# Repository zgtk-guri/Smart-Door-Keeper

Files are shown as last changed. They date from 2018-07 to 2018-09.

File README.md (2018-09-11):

### トランジスタ技術 IoT製作コーナー
## NFCカードリーダ×Wi-Fi/Bluetoothマイコンで作るIoT電子錠
# 「Smart Door Keeper」ダウンロードページ

## 2018年9月号 前編 NFCの仕組みとハードウェア製作
* [3Dプリントファイル](3DPrint/README.md)
* [回路図・基板パターン](Circuit/README.md)

## 2018年10月号 後編
* [ESP32のプログラム(Platform IO, Arduino Core使用)](https://github.com/zgtk-guri/Smart-Door-Keeper-ESP32/tree/toragi1810)
* [Androidアプリのプログラム](https://github.com/zgtk-guri/Smart-Door-Keeper-Android/tree/toragi1810)

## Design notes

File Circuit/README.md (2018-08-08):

# Smart Door Keeper 回路図・基板パターンファイル

* [SmartDoorKeeper.pro](SmartDoorKeeper.pro) KiCad 4.0.7 プロジェクトファイル
* [SmartDoorKeeper.sch](SmartDoorKeeper.sch) Eeschema 回路図ファイル
* [SmartDoorKeeper-schematic.pdf](SmartDoorKeeper-schematic.pdf) 回路図PDFファイル
* [SmartDoorKeeper.kicad_pcb](SmartDoorKeeper.kicad_pcb) Pcbnew 基板パターンファイル

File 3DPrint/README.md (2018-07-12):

# Smart Door Keyper 3Dプリントファイル

* SOLIDWORKS 2017で設計
* 3Dプリンタで出力する際に，サポート材が生成されないように分割ししてSTLにしている部品がある

## 分解図（組み立てイメージ）
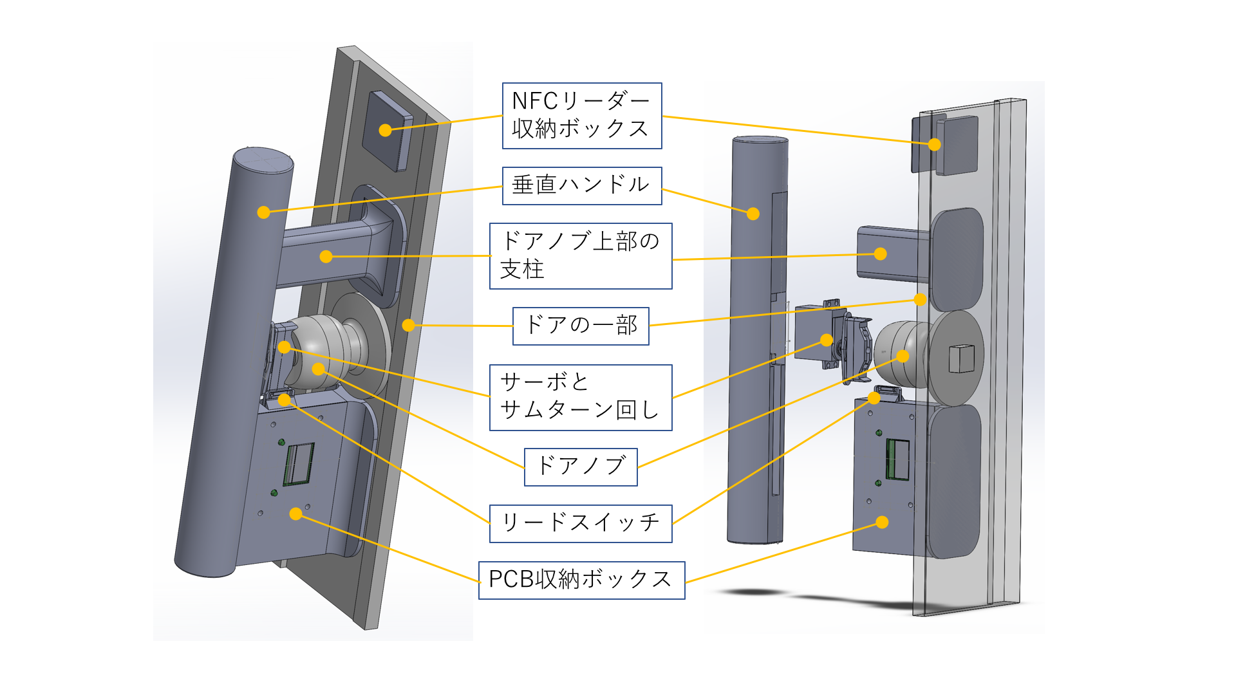
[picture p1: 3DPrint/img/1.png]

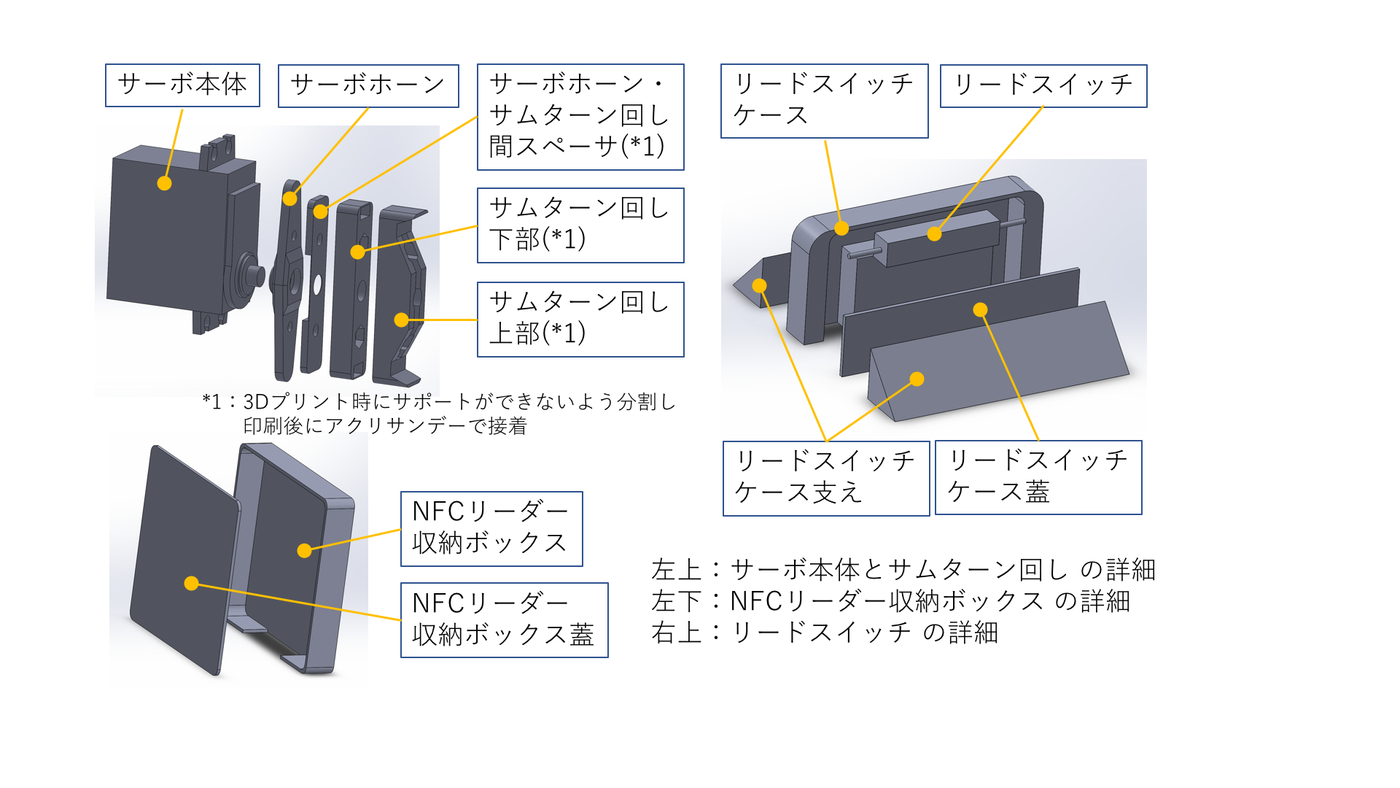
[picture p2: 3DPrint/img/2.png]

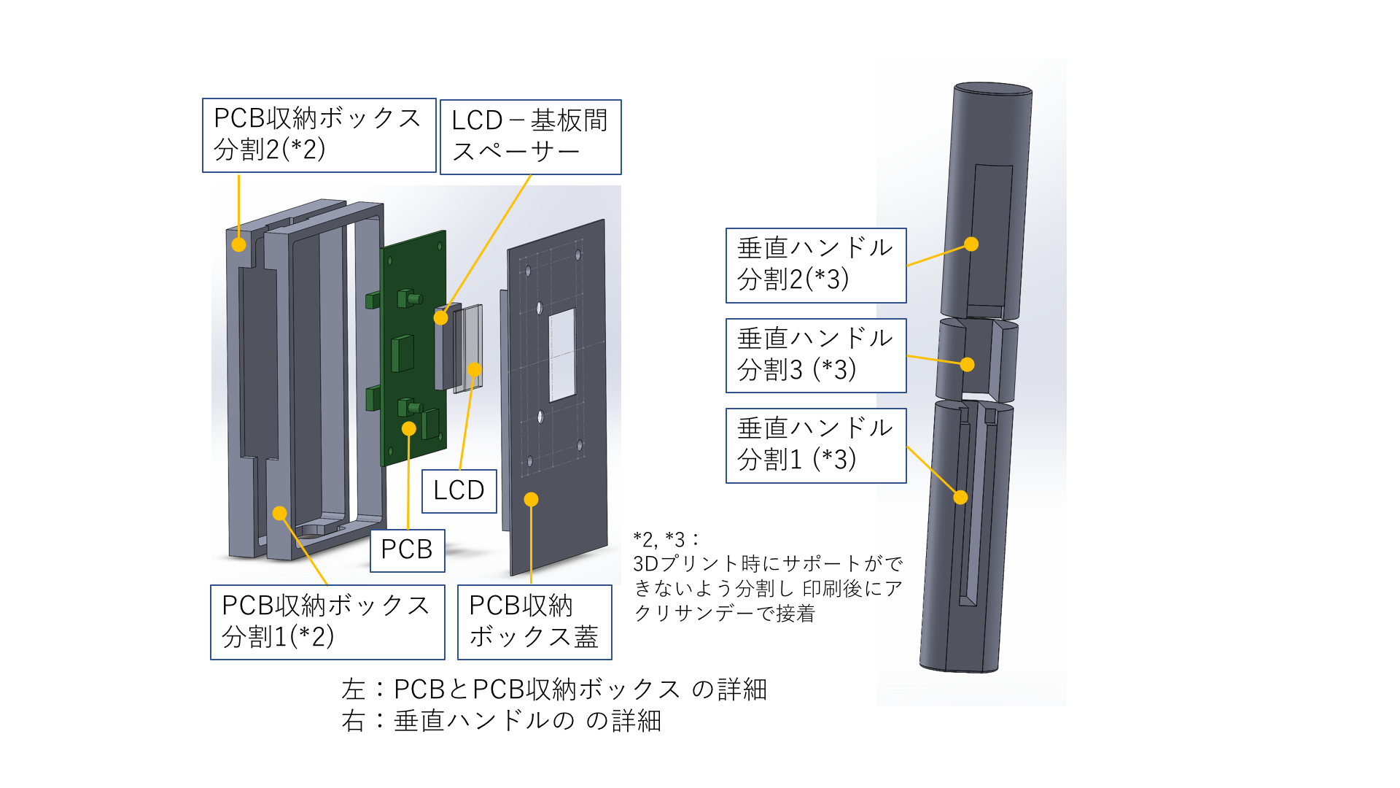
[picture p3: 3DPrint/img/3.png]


## ファイル一覧

<table>
  <tr>
    <th colspan="3">SolidWorks2017で作成した図面</th>
    <th colspan="2">3Dプリンタ用STLファイル</th>
  </tr>
  <tr>
    <td><a href="Solidworks/AssemDoorAndServo.SLDASM">AssemDoorAndServo.SLDASM</a>
    <td>組立図</td>
    <td>全組立図</td>
    <td></td>
    <td></td>
  </tr>
  <tr>
    <td><a href="Solidworks/AssemDoorKnob.SLDASM">AssemDoorKnob.SLDASM</a>
    <td>組立図</td>
    <td>ドアノブ</td>
    <td></td>
    <td></td>
  </tr>
  <tr>
    <td><a href="Solidworks/AssemNfcBox.SLDASM">AssemNfcBox.SLDASM</a>
    <td>組立図</td>
    <td>NFCリーダー収納ボックス</td>
    <td></td>
    <td></td>
  </tr>
  <tr>
    <td><a href="Solidworks/AssemPrintCircuitBoardAndLid.SLDASM">AssemPrintCircuitBoardAndLid.SLDASM</a>
    <td>組立図</td>
    <td>基板と基板収納ボックスの蓋</td>
    <td></td>
    <td></td>
  </tr>
  <tr>
    <td><a href="Solidworks/AssemPrintCircuitBoardBox.SLDASM">AssemPrintCircuitBoardBox.SLDASM</a>
    <td>組立図</td>
    <td>基板収納ボックスと基板</td>
    <td></td>
    <td></td>
  </tr>
  <tr>
    <td><a href="Solidworks/AssemPrintCuircuitBoard.SLDASM">AssemPrintCuircuitBoard.SLDASM</a>
    <td>組立図</td>
    <td>PCB</td>
    <td></td>
    <td></td>
  </tr>
  <tr>
    <td><a href="Solidworks/AssemReedSwitchCase.SLDASM">AssemReedSwitchCase.SLDASM</a>
    <td>組立図</td>
    <td>リードスイッチとケース</td>
    <td></td>
    <td></td>
  </tr>
  <tr>
    <td><a href="Solidworks/AssemServo.SLDASM">AssemServo.SLDASM</a>
    <td>組立図</td>
    <td>サーボとサムターン回し</td>
    <td></td>
    <td></td>
  </tr>
  <tr>
    <td><a href="Solidworks/door.SLDPRT">door.SLDPRT</a>
    <td>部品図</td>
    <td>ドア（の一部）</td>
    <td></td>
    <td></td>
  </tr>
  <tr>
    <td rowspan="3"><a href="Solidworks/HandleVertical.SLDPRT">HandleVertical.SLDPRT</a>
    <td rowspan="3">部品図</td>
    <td rowspan="3">垂直ハンドル</td>
    <td><a href="STL/HandleVertical1.STL">HandleVertical1.STL</a>
    <td>垂直ハンドル分割1</td>
  </tr>
  <tr>
    <td><a href="STL/HandleVertical2.STL">HandleVertical2.STL</a>
    <td>垂直ハンドル分割2</td>
  </tr>
  <tr>
    <td><a href="STL/HandleVertical3.STL">HandleVertical3.STL</a>
    <td>垂直ハンドル分割3</td>
  </tr>
  <tr>
    <td><a href="Solidworks/Knob.SLDPRT">Knob.SLDPRT</a>
    <td>部品図</td>
    <td>ドアノブ</td>
    <td></td>
    <td></td>
  </tr>
  <tr>
    <td><a href="Solidworks/KnobUpper.SLDPRT">KnobUpper.SLDPRT</a>
    <td>部品図</td>
    <td>ドアノブ上部の支柱</td>
    <td><a href="STL/KnobUpper.STL">KnobUpper.STL</a>
    <td>ドアノブ上部の支柱</td>
  </tr>
  <tr>
    <td><a href="Solidworks/LCD.SLDPRT">LCD.SLDPRT</a>
    <td>部品図</td>
    <td>LCD</td>
    <td></td>
    <td></td>
  </tr>
  <tr>
    <td><a href="Solidworks/LcdSpacer.SLDPRT">LcdSpacer.SLDPRT</a>
    <td>部品図</td>
    <td>LCD－基板間スペーサー</td>
    <td><a href="STL/LcdSpacer.STL">LcdSpacer.STL</a>
    <td>LCD－基板間スペーサー</td>
  </tr>
  <tr>
    <td><a href="Solidworks/NfcBox.SLDPRT">NfcBox.SLDPRT</a>
    <td>部品図</td>
    <td>NFCリーダー収納ボックス</td>
    <td><a href="STL/NfcBox.STL">NfcBox.STL</a>
    <td>NFCリーダー収納ボックス</td>
  </tr>
  <tr>
    <td><a href="Solidworks/NfcBoxLid.SLDPRT">NfcBoxLid.SLDPRT</a>
    <td>部品図</td>
    <td>NFCリーダー収納ボックス蓋</td>
    <td><a href="STL/NfcBoxLid.STL">NfcBoxLid.STL</a>
    <td>NFCリーダー収納ボックス蓋</td>
  </tr>
  <tr>
    <td><a href="Solidworks/PrintCircuitBoard.SLDPRT">PrintCircuitBoard.SLDPRT</a>
    <td>部品図</td>
    <td>PCB</td>
    <td></td>
    <td></td>
  </tr>
  <tr>
    <td rowspan="2"><a href="Solidworks/PrintCircuitBoardBox.SLDPRT">PrintCircuitBoardBox.SLDPRT</a>
    <td rowspan="2">部品図</td>
    <td rowspan="2">PCB収納ボックス</td>
    <td><a href="STL/PrintCircuitBoardBox1.STL">PrintCircuitBoardBox1.STL</a>
    <td>PCB収納ボックス分割1</td>
  </tr>
  <tr>
    <td><a href="STL/PrintCircuitBoardBox2.STL">PrintCircuitBoardBox2.STL</a>
    <td>PCB収納ボックス分割2</td>
  </tr>
  <tr>
    <td><a href="Solidworks/PrintCircuitBoardLid.SLDPRT">PrintCircuitBoardLid.SLDPRT</a>
    <td>部品図</td>
    <td>PCB収納ボックス蓋</td>
    <td><a href="STL/PrintCircuitBoardLid.STL">PrintCircuitBoardLid.STL</a>
    <td>PCB収納ボックス蓋</td>
  </tr>
  <tr>
    <td><a href="Solidworks/PrintCircuitBoardSpacer.SLDPRT">PrintCircuitBoardSpacer.SLDPRT</a>
    <td>部品図</td>
    <td>PCB収納ボックスとドアの間のスペーサ</td>
    <td><a href="STL/PrintCircuitBoardSpacer.STL">PrintCircuitBoardSpacer.STL</a>
    <td>PCB収納ボックスとドアの間のスペーサ</td>
  </tr>
  <tr>
    <td><a href="Solidworks/ReadSwitchBox.SLDPRT">ReadSwitchBox.SLDPRT</a>
    <td>部品図</td>
    <td>リードスイッチケース</td>
    <td><a href="STL/ReadSwitchBox.STL">ReadSwitchBox.STL</a>
    <td>リードスイッチケース</td>
  </tr>
  <tr>
    <td><a href="Solidworks/ReadSwitchLid.SLDPRT">ReadSwitchLid.SLDPRT</a>
    <td>部品図</td>
    <td>リードスイッチケース蓋</td>
    <td><a href="STL/ReadSwitchLid.STL">ReadSwitchLid.STL</a>
    <td>リードスイッチケース蓋</td>
  </tr>
  <tr>
    <td><a href="Solidworks/ReedSwitch.SLDPRT">ReedSwitch.SLDPRT</a>
    <td>部品図</td>
    <td>リードスイッチ</td>
    <td></td>
    <td></td>
  </tr>
  <tr>
    <td><a href="Solidworks/RotaterOfThumbTurnLower.SLDPRT">RotaterOfThumbTurnLower.SLDPRT</a>
    <td>部品図</td>
    <td>サムターン回し下部</td>
    <td><a href="STL/RotaterOfThumbTurnLower.STL">RotaterOfThumbTurnLower.STL</a>
    <td>サムターン回し下部</td>
  </tr>
  <tr>
    <td><a href="Solidworks/RotaterOfThumbTurnUpper.SLDPRT">RotaterOfThumbTurnUpper.SLDPRT</a>
    <td>部品図</td>
    <td>サムターン回し上部</td>
    <td><a href="STL/RotaterOfThumbTurnUpper.STL">RotaterOfThumbTurnUpper.STL</a>
    <td>サムターン回し上部</td>
  </tr>
  <tr>
    <td rowspan="2"><a href="Solidworks/SensorFoot.SLDPRT">SensorFoot.SLDPRT</a>
    <td rowspan="2">部品図</td>
    <td rowspan="2">リードスイッチケース支え</td>
    <td><a href="STL/SensorFoot1.STL">SensorFoot1.STL</a>
    <td>リードスイッチケース支え</td>
  </tr>
  <tr>
    <td><a href="STL/SensorFoot2.STL">SensorFoot2.STL</a>
    <td>リードスイッチケース支え</td>
  </tr>
  <tr>
    <td><a href="Solidworks/ServoArm.SLDPRT">ServoArm.SLDPRT</a>
    <td>部品図</td>
    <td>サーボホーン</td>
    <td></td>
    <td></td>
  </tr>
  <tr>
    <td><a href="Solidworks/ServoBody.SLDPRT">ServoBody.SLDPRT</a>
    <td>部品図</td>
    <td>サーボ本体</td>
    <td></td>
    <td></td>
  </tr>
  <tr>
    <td><a href="Solidworks/sumTurn.SLDPRT">sumTurn.SLDPRT</a>
    <td>部品図</td>
    <td>サムターン</td>
    <td></td>
    <td></td>
  </tr>
  <tr>
    <td><a href="Solidworks/WasherSpecialServo.SLDPRT">WasherSpecialServo.SLDPRT</a>
    <td>部品図</td>
    <td>サーボホーン・サムターン回し間スペーサ</td>
    <td><a href="STL/WasherSpecialServo.STL">WasherSpecialServo.STL</a>
    <td>サーボホーン・サムターン回し間スペーサ</td>
  </tr>
</table>

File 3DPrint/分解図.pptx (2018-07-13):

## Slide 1

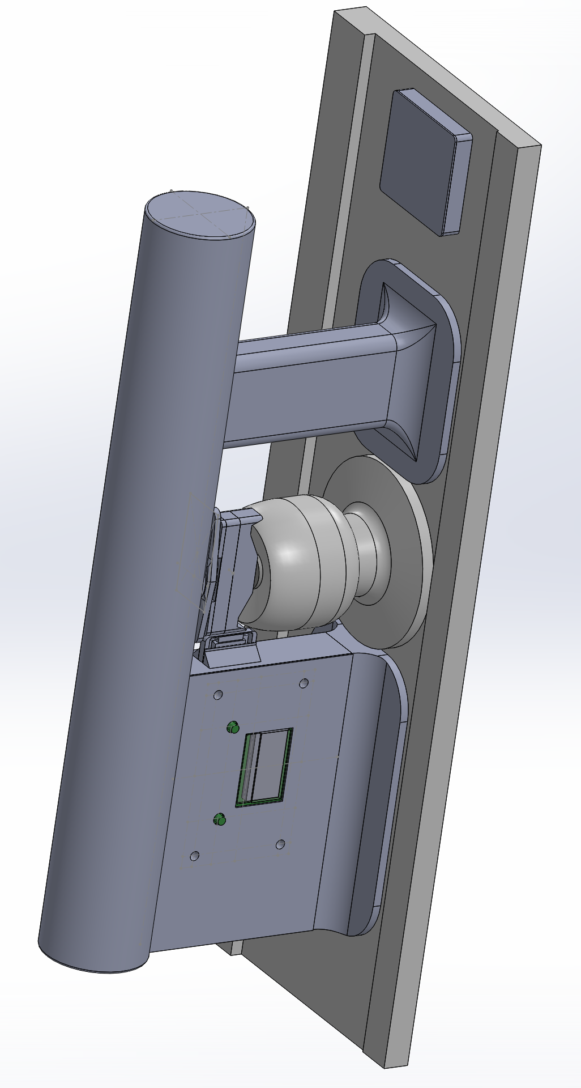
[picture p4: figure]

NFCリーダー
収納ボックス

垂直ハンドル

ドアノブ上部の
支柱

ドアの一部

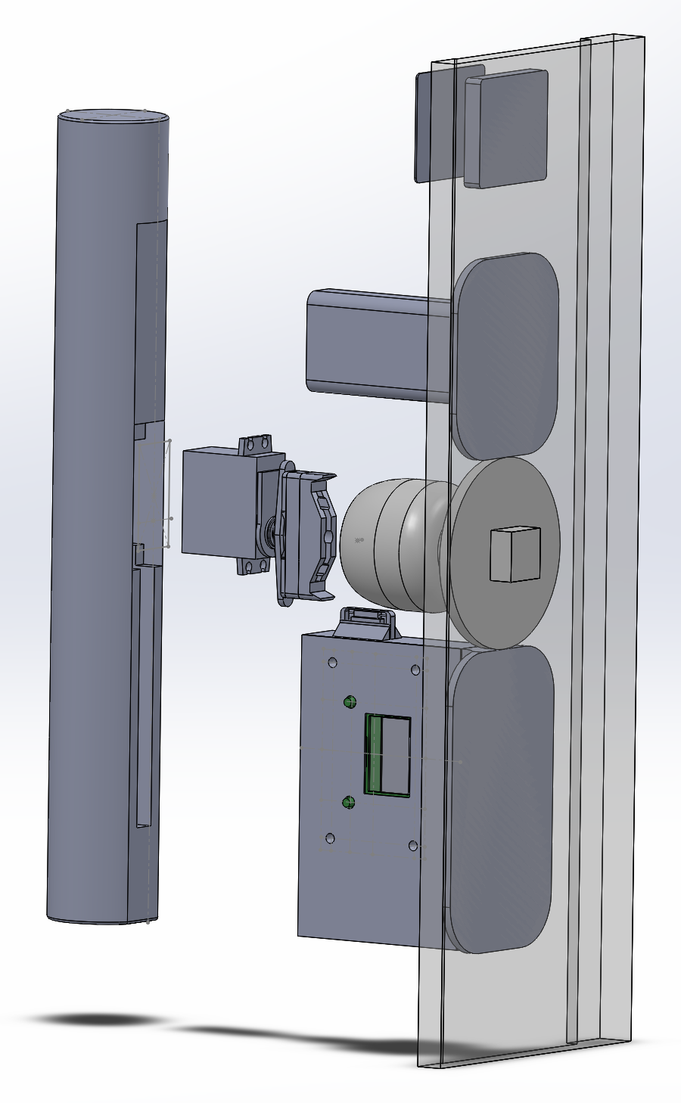
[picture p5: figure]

サーボと
サムターン回し

ドアノブ

リードスイッチ

PCB収納ボックス

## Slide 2

サーボ本体

サーボホーン

サーボホーン・
サムターン回し
間スペーサ(*1)

サムターン回し
下部(*1)

リードスイッチ
ケース

リードスイッチ

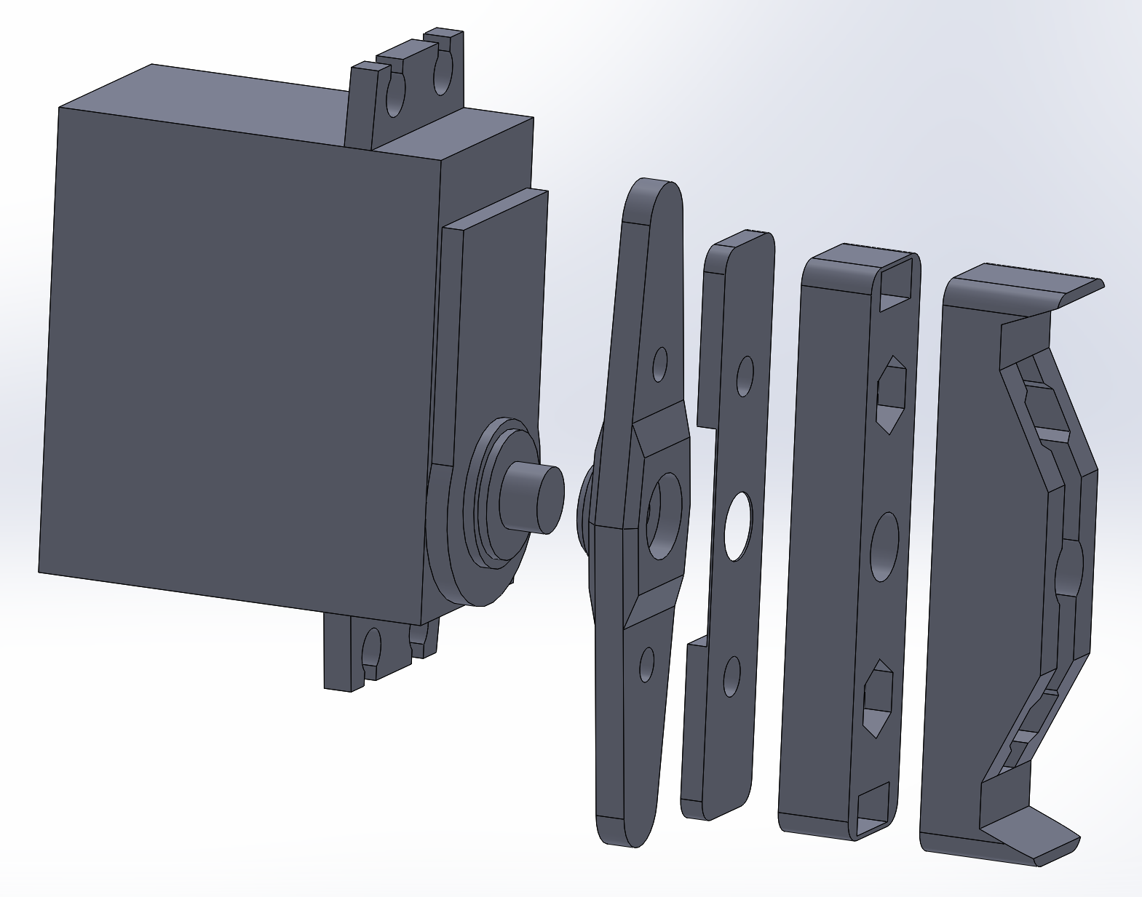
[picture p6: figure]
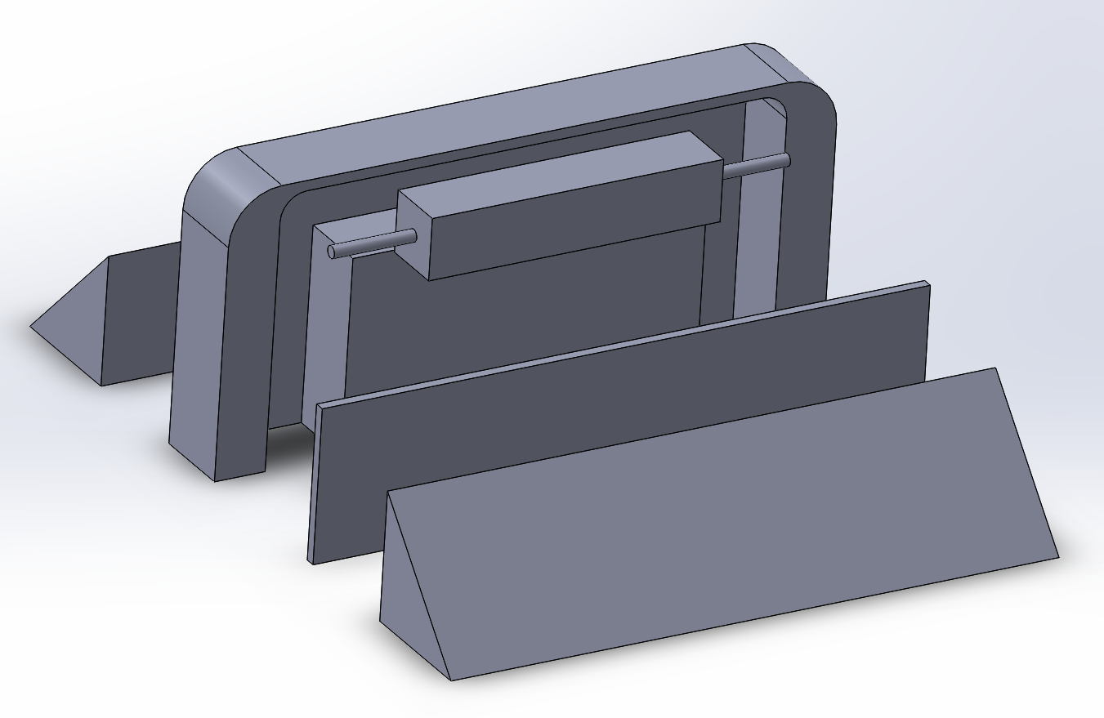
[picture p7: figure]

サムターン回し
上部(*1)

*1：3Dプリント時にサポートができないよう分割し
印刷後にアクリサンデーで接着

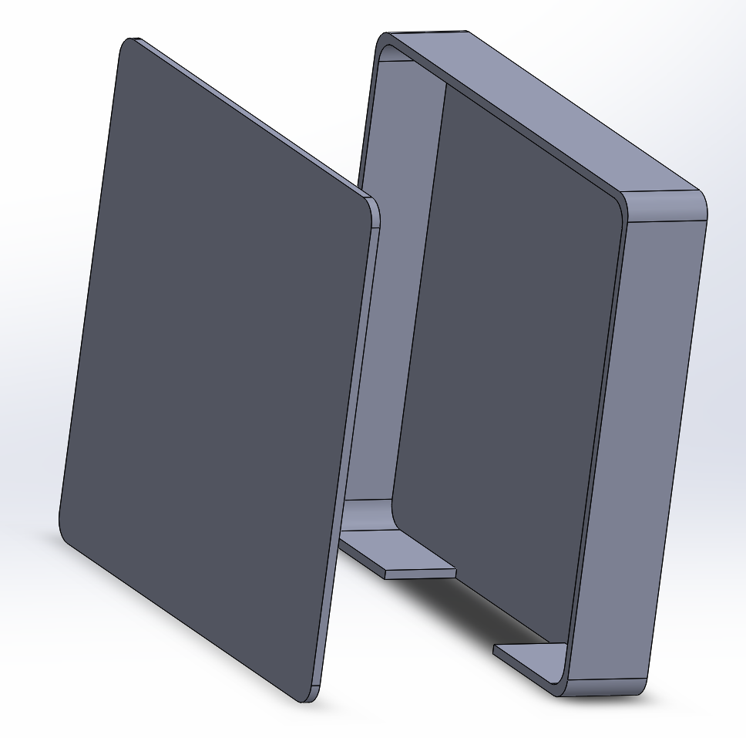
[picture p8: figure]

リードスイッチ
ケース支え

リードスイッチ
ケース蓋

NFCリーダー
収納ボックス

NFCリーダー
収納ボックス蓋

左上：サーボ本体とサムターン回し の詳細
左下：NFCリーダー収納ボックス の詳細
右上：リードスイッチ の詳細

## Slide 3

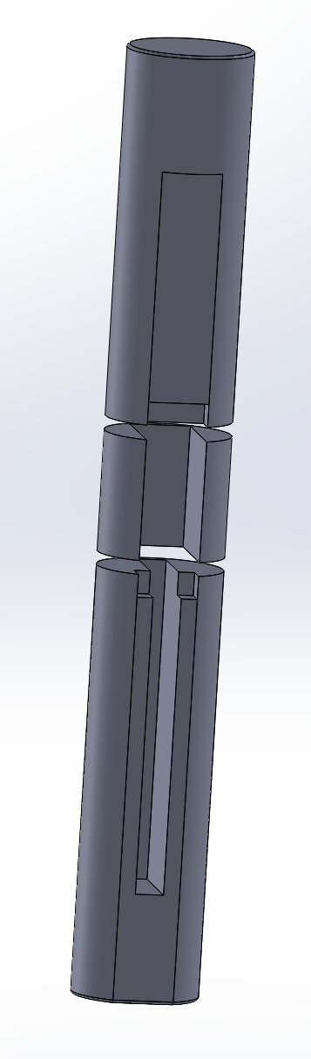
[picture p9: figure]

PCB収納ボックス
分割2(*2)

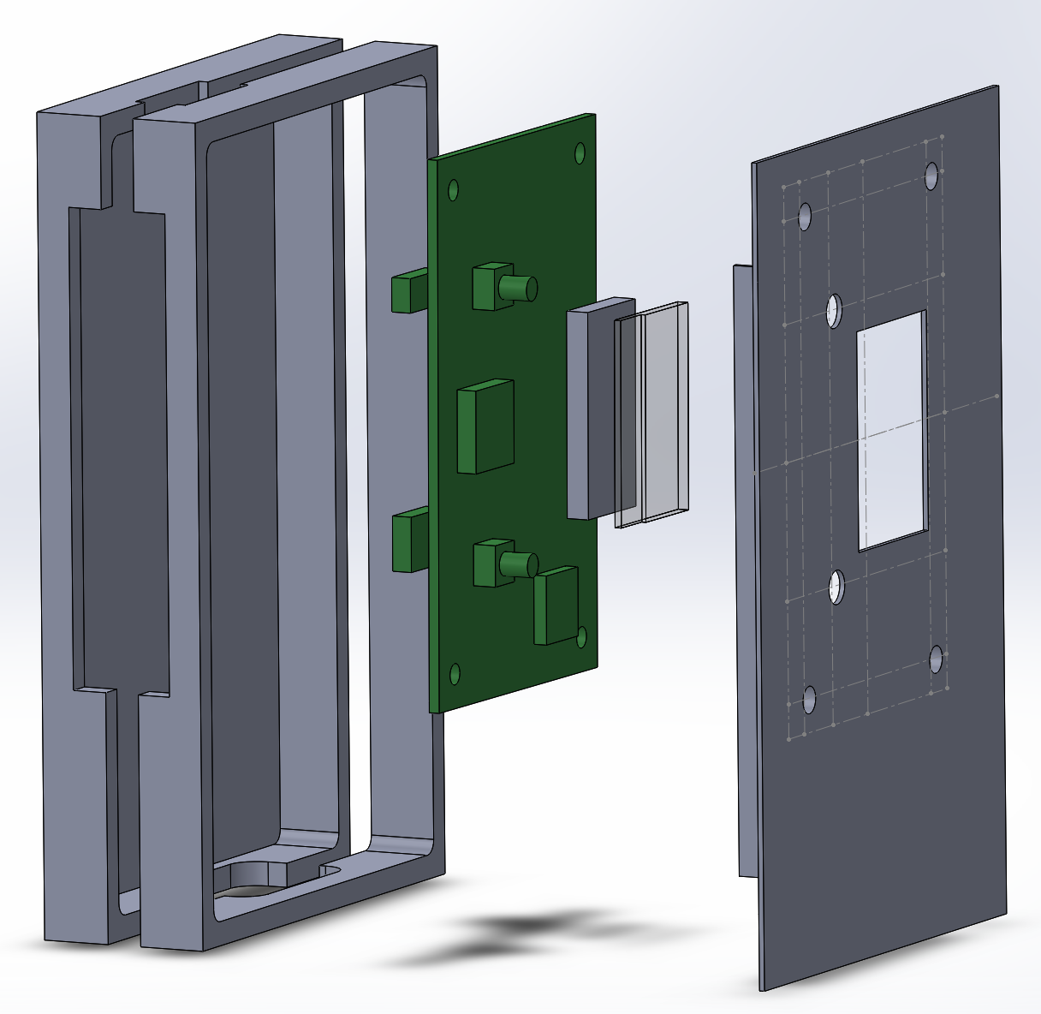
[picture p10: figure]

PCB収納ボックス
分割1(*2)

LCD－基板間
スペーサー

垂直ハンドル
分割2(*3)

垂直ハンドル
分割3 (*3)

垂直ハンドル
分割1 (*3)

*2, *3：
3Dプリント時にサポートができないよう分割し 印刷後にアクリサンデーで接着

LCD

PCB

PCB収納
ボックス蓋

左：PCBとPCB収納ボックス の詳細
右：垂直ハンドルの の詳細

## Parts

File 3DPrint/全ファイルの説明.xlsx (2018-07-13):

SolidWorks2017で作成した図面 |  |  | 3Dプリンタ用STLファイル
AssemDoorAndServo.SLDASM | 組立図 | 全組立図
AssemDoorKnob.SLDASM | 組立図 | ドアノブ
AssemNfcBox.SLDASM | 組立図 | NFCリーダー収納ボックス
AssemPrintCircuitBoardAndLid.SLDASM | 組立図 | 基板と基板収納ボックスの蓋
AssemPrintCircuitBoardBox.SLDASM | 組立図 | 基板収納ボックスと基板 | STLファイルの補足： サポートを作らないようにするためSTLファイルを分割作成した部品がある。 SensorFoot1とSensorFoot2は全く同じ部品。2個必要なためファイルを2つ用意し全て1個印刷。 筆者はMakerBot Replicator2xを使用してプリント。アクリサンデーで接着。
AssemPrintCuircuitBoard.SLDASM | 組立図 | PCB
AssemReedSwitchCase.SLDASM | 組立図 | リードスイッチとケース
AssemServo.SLDASM | 組立図 | サーボとサムターン回し
door.SLDPRT | 部品図 | ドア（の一部）
HandleVertical.SLDPRT | 部品図 | 垂直ハンドル | HandleVertical1.STL | 垂直ハンドル分割1
 |  |  | HandleVertical2.STL | 垂直ハンドル分割2
 |  |  | HandleVertical3.STL | 垂直ハンドル分割3
Knob.SLDPRT | 部品図 | ドアノブ
KnobUpper.SLDPRT | 部品図 | ドアノブ上部の支柱 | KnobUpper.STL | ドアノブ上部の支柱
LCD.SLDPRT | 部品図 | LCD
LcdSpacer.SLDPRT | 部品図 | LCD－基板間スペーサー | LcdSpacer.STL | LCD－基板間スペーサー
NfcBox.SLDPRT | 部品図 | NFCリーダー収納ボックス | NfcBox.STL | NFCリーダー収納ボックス
NfcBoxLid.SLDPRT | 部品図 | NFCリーダー収納ボックス蓋 | NfcBoxLid.STL | NFCリーダー収納ボックス蓋
PrintCircuitBoard.SLDPRT | 部品図 | PCB
PrintCircuitBoardBox.SLDPRT | 部品図 | PCB収納ボックス | PrintCircuitBoardBox1.STL | PCB収納ボックス分割1
 |  |  | PrintCircuitBoardBox2.STL | PCB収納ボックス分割2
PrintCircuitBoardLid.SLDPRT | 部品図 | PCB収納ボックス蓋 | PrintCircuitBoardLid.STL | PCB収納ボックス蓋
PrintCircuitBoardSpacer.SLDPRT | 部品図 | PCB収納ボックスとドアの間のスペーサ | PrintCircuitBoardSpacer.STL | PCB収納ボックスとドアの間のスペーサ
ReadSwitchBox.SLDPRT | 部品図 | リードスイッチケース | ReadSwitchBox.STL | リードスイッチケース
ReadSwitchLid.SLDPRT | 部品図 | リードスイッチケース蓋 | ReadSwitchLid.STL | リードスイッチケース蓋
ReedSwitch.SLDPRT | 部品図 | リードスイッチ | RotaterOfThumbTurnLower.STL | サムターン回し下部
RotaterOfThumbTurnLower.SLDPRT | 部品図 | サムターン回し下部
RotaterOfThumbTurnUpper.SLDPRT | 部品図 | サムターン回し上部 | RotaterOfThumbTurnUpper.STL | サムターン回し上部
SensorFoot.SLDPRT | 部品図 | リードスイッチケース支え | SensorFoot1.STL | リードスイッチケース支え
 |  |  | SensorFoot2.STL | リードスイッチケース支え
ServoArm.SLDPRT | 部品図 | サーボホーン
ServoBody.SLDPRT | 部品図 | サーボ本体
sumTurn.SLDPRT | 部品図 | サムターン
WasherSpecialServo.SLDPRT | 部品図 | サーボホーン・サムターン回し間スペーサ | WasherSpecialServo.STL | サーボホーン・サムターン回し間スペーサ
smartDoorKeyper.pptx | 分解図 | 各部を分解した図（組立の参考）

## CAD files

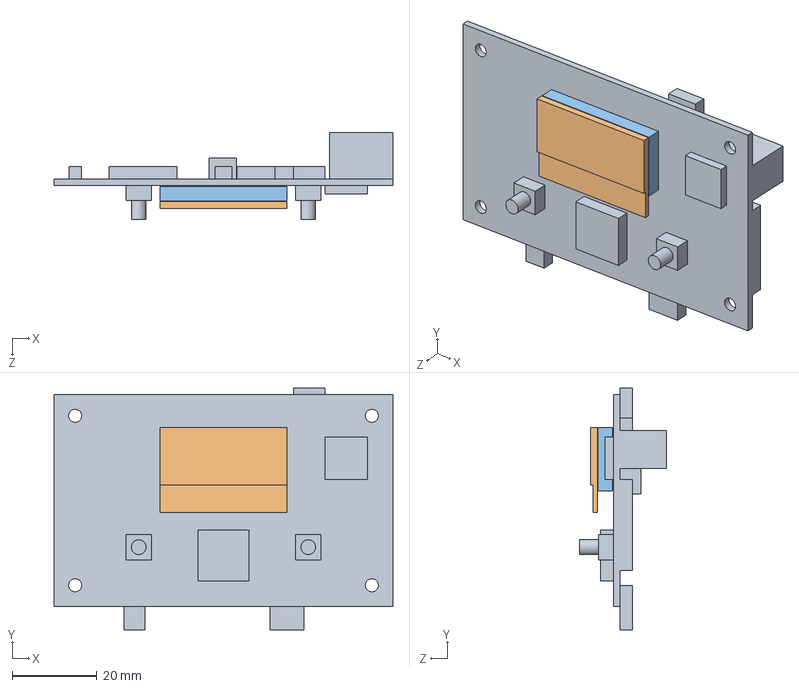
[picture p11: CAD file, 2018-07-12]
3DPrint/Solidworks/AssemPrintCuircuitBoard.SLDASM
80.0 x 57.0 x 20.6 mm
PrintCircuitBoard
LCD
LcdSpacer

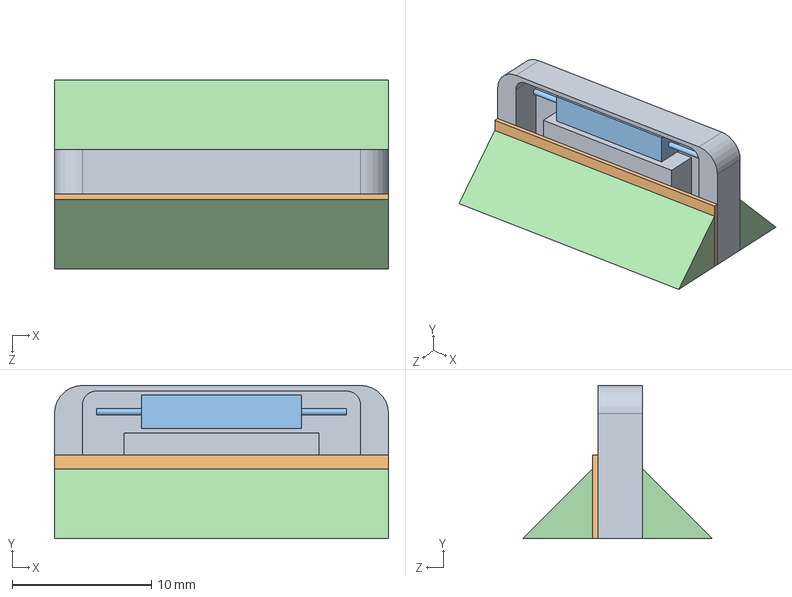
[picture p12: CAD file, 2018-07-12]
3DPrint/Solidworks/AssemReedSwitchCase.SLDASM
24.0 x 11.0 x 13.6 mm
ReadSwitchBox
ReadSwitchLid
ReedSwitch
SensorFoot x 2

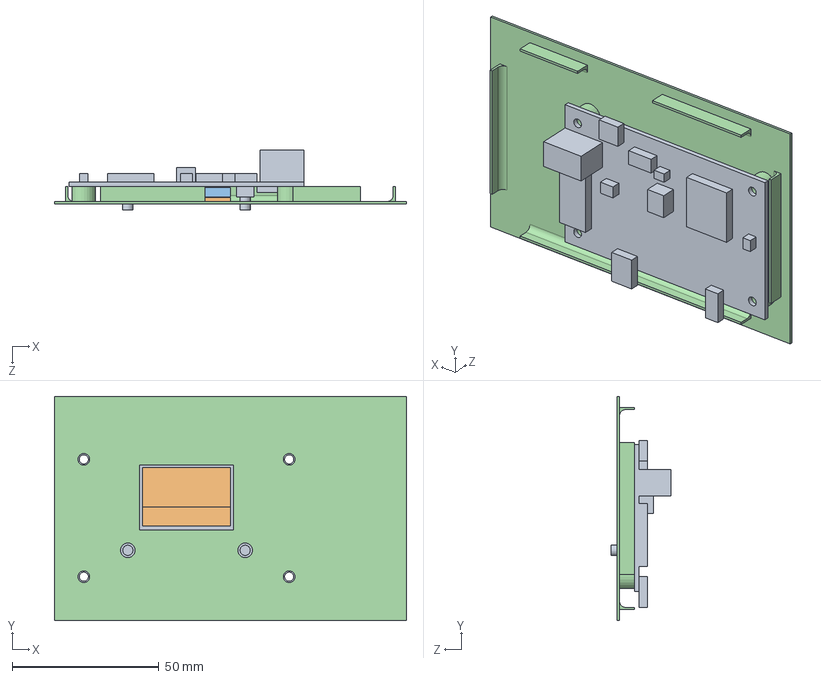
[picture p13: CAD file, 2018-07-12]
3DPrint/Solidworks/AssemPrintCircuitBoardAndLid.SLDASM
120.0 x 76.5 x 20.6 mm
PrintCircuitBoard
LCD
LcdSpacer
PrintCircuitBoardLid

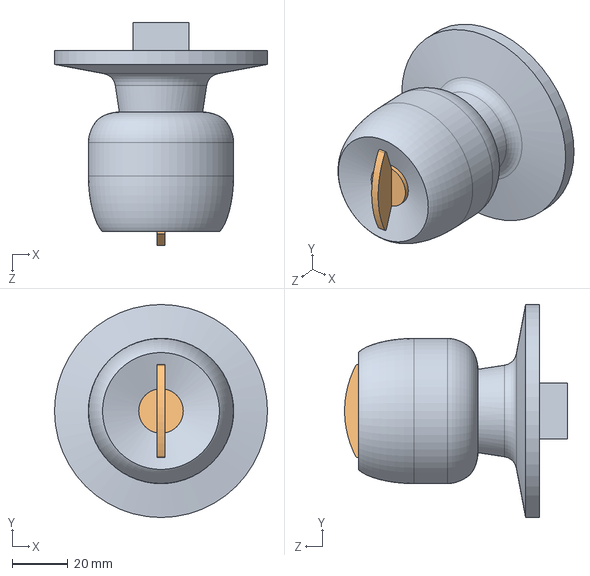
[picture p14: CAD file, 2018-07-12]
3DPrint/Solidworks/AssemDoorKnob.SLDASM
76.5 x 76.5 x 80.0 mm
Knob
sumTurn

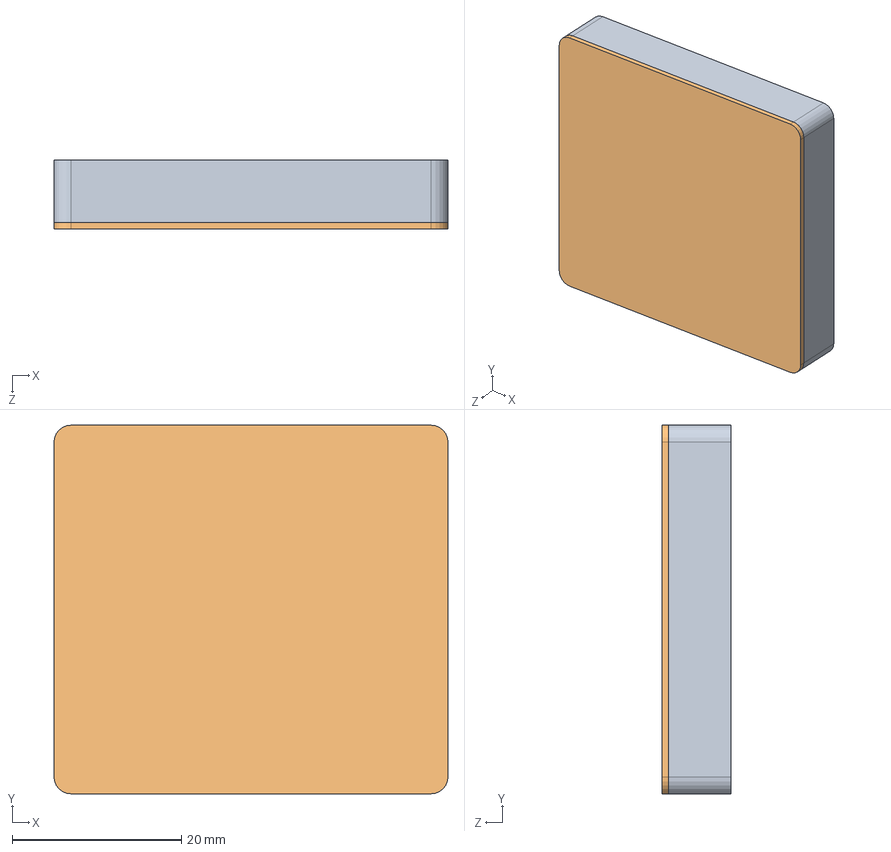
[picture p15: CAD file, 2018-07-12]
3DPrint/Solidworks/AssemNfcBox.SLDASM
46.6 x 43.6 x 8.20 mm
NfcBox
NfcBoxLid

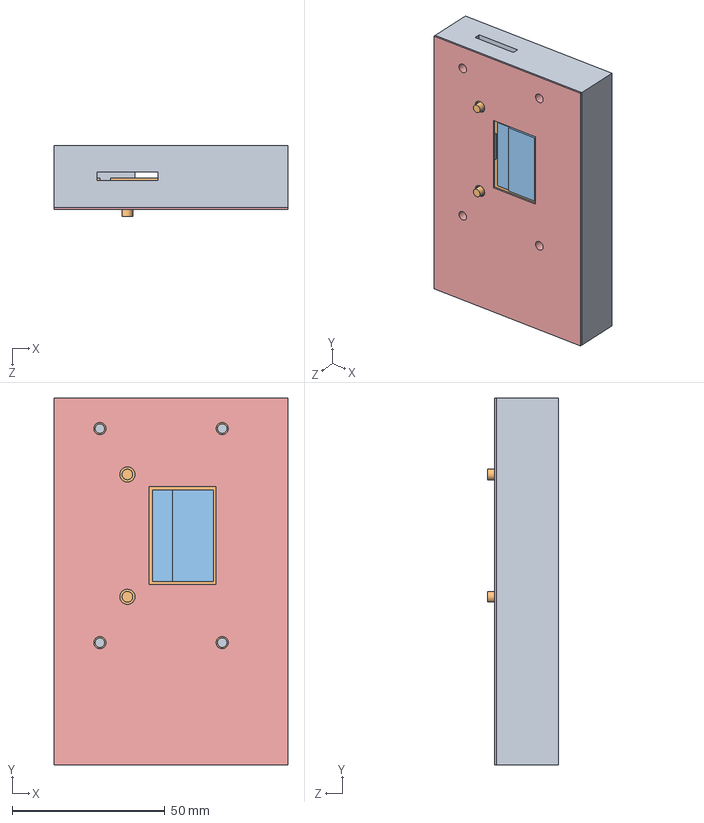
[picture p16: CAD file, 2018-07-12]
3DPrint/Solidworks/AssemPrintCircuitBoardBox.SLDASM
76.5 x 120.0 x 23.2 mm
PrintCircuitBoardBox
PrintCircuitBoard
LCD
LcdSpacer
PrintCircuitBoardLid

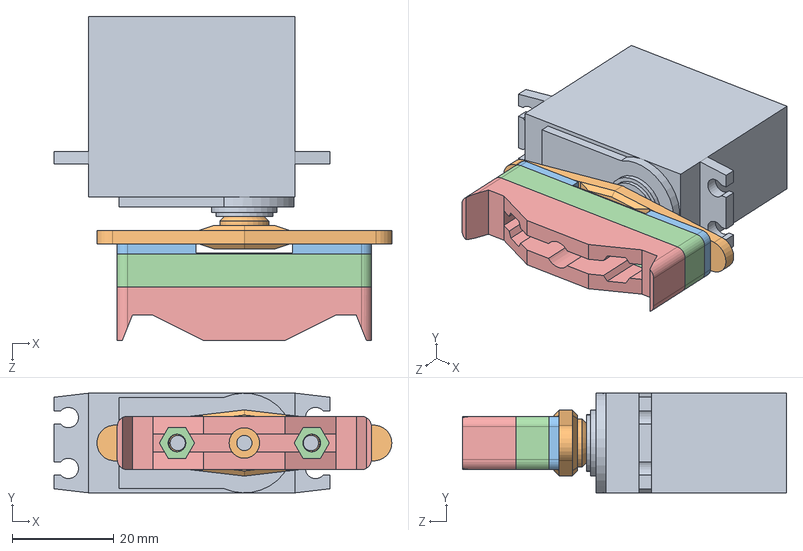
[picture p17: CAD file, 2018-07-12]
3DPrint/Solidworks/AssemServo.SLDASM
66.4 x 19.6 x 63.7 mm
ServoBody
ServoArm
WasherSpecialServo
RotaterOfThumbTurnLower
RotaterOfThumbTurnUpper

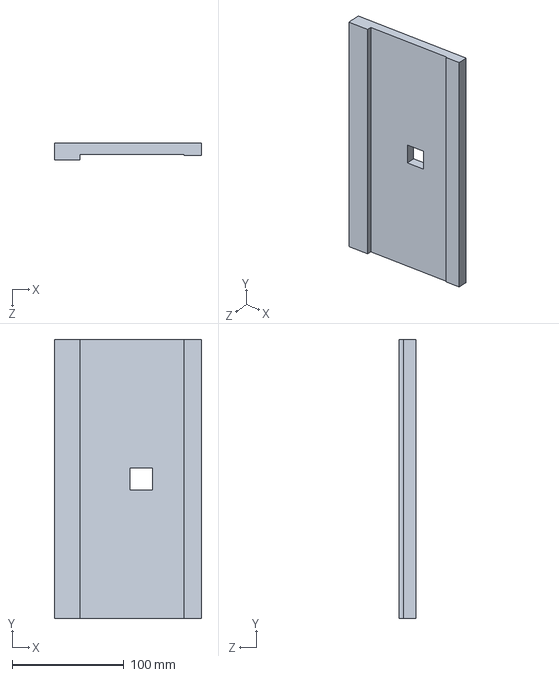
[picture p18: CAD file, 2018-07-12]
3DPrint/Solidworks/door.SLDPRT
132.0 x 250.0 x 15.0 mm

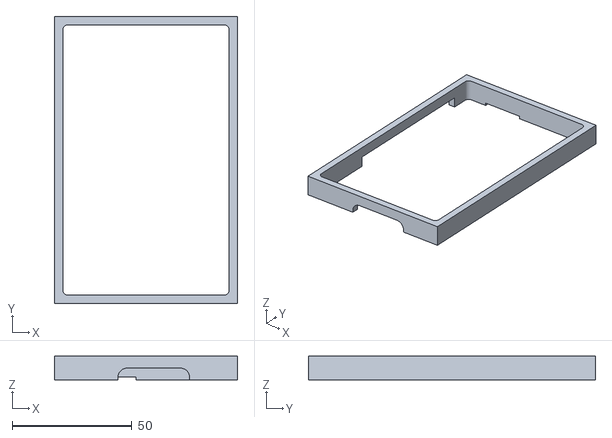
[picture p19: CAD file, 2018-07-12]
3DPrint/STL/PrintCircuitBoardBox1.STL
76.5 x 120.0 x 10.00

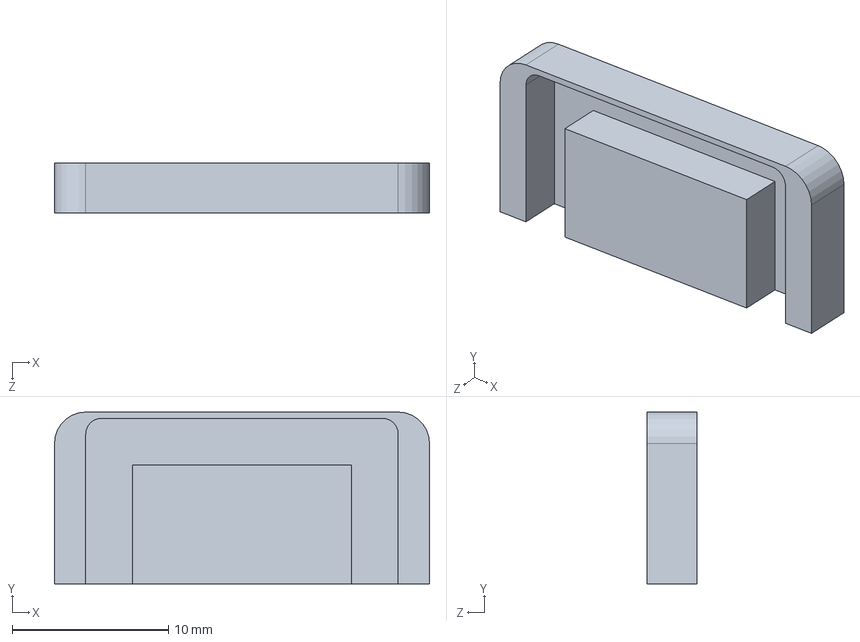
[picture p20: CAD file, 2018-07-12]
3DPrint/Solidworks/ReadSwitchBox.SLDPRT
24.0 x 11.0 x 3.20 mm

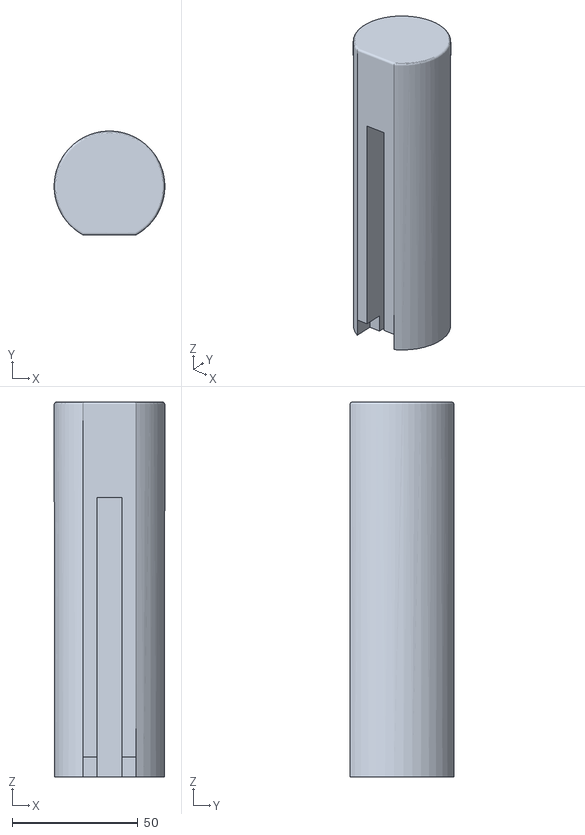
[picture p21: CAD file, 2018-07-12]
3DPrint/STL/HandleVertical1.STL
43.9 x 41.3 x 149.0

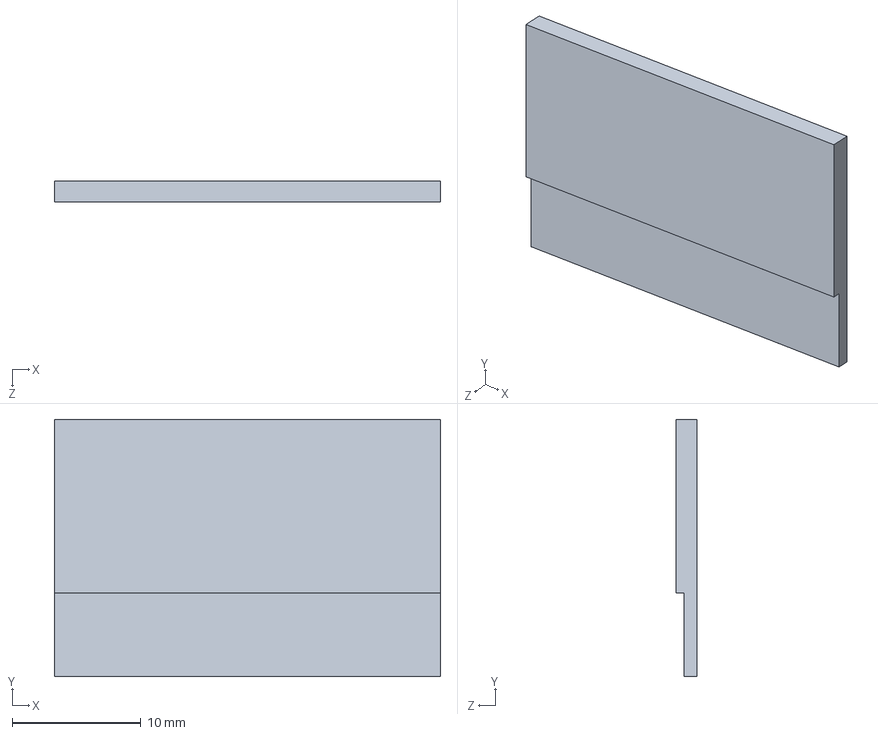
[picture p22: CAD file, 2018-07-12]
3DPrint/Solidworks/LCD.SLDPRT
30.0 x 20.0 x 1.65 mm

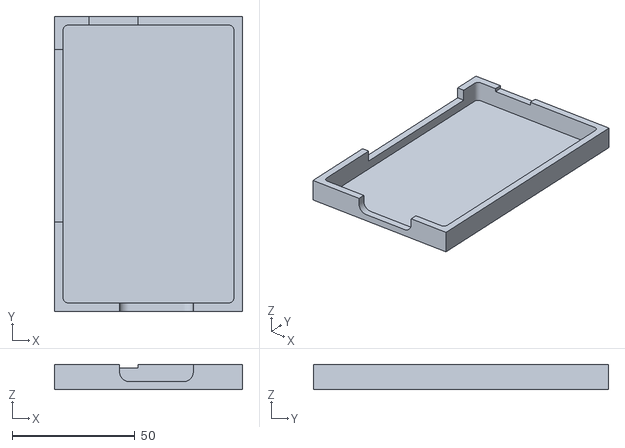
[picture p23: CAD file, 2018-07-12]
3DPrint/STL/PrintCircuitBoardBox2.STL
76.5 x 120.0 x 10.2

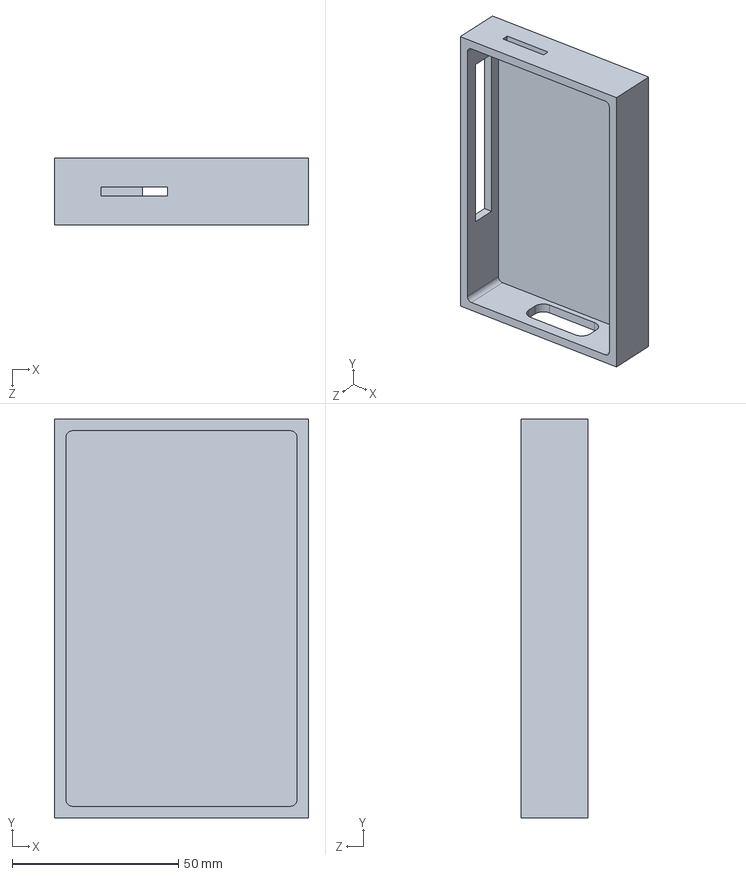
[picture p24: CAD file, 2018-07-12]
3DPrint/Solidworks/PrintCircuitBoardBox.SLDPRT
76.5 x 120.0 x 20.2 mm

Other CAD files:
3DPrint/STL/HandleVertical2.STL
3DPrint/STL/HandleVertical3.STL
3DPrint/Solidworks/KnobUpper.SLDPRT
3DPrint/STL/KnobUpper.STL
3DPrint/STL/LcdSpacer.STL
3DPrint/STL/NfcBox.STL
3DPrint/STL/NfcBoxLid.STL
3DPrint/STL/PrintCircuitBoardLid.STL
3DPrint/STL/PrintCircuitBoardSpacer.STL
3DPrint/STL/ReadSwitchBox.STL
3DPrint/STL/ReadSwitchLid.STL
3DPrint/STL/RotaterOfThumbTurnLower.STL
3DPrint/STL/RotaterOfThumbTurnUpper.STL
3DPrint/STL/SensorFoot1.STL
3DPrint/STL/SensorFoot2.STL
3DPrint/STL/WasherSpecialServo.STL
3DPrint/Solidworks/HandleVertical.SLDPRT
3DPrint/Solidworks/Knob.SLDPRT
3DPrint/Solidworks/LcdSpacer.SLDPRT
3DPrint/Solidworks/NfcBox.SLDPRT
3DPrint/Solidworks/NfcBoxLid.SLDPRT
3DPrint/Solidworks/PrintCircuitBoard.SLDPRT
3DPrint/Solidworks/PrintCircuitBoardLid.SLDPRT
3DPrint/Solidworks/PrintCircuitBoardSpacer.SLDPRT
3DPrint/Solidworks/ReadSwitchLid.SLDPRT
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

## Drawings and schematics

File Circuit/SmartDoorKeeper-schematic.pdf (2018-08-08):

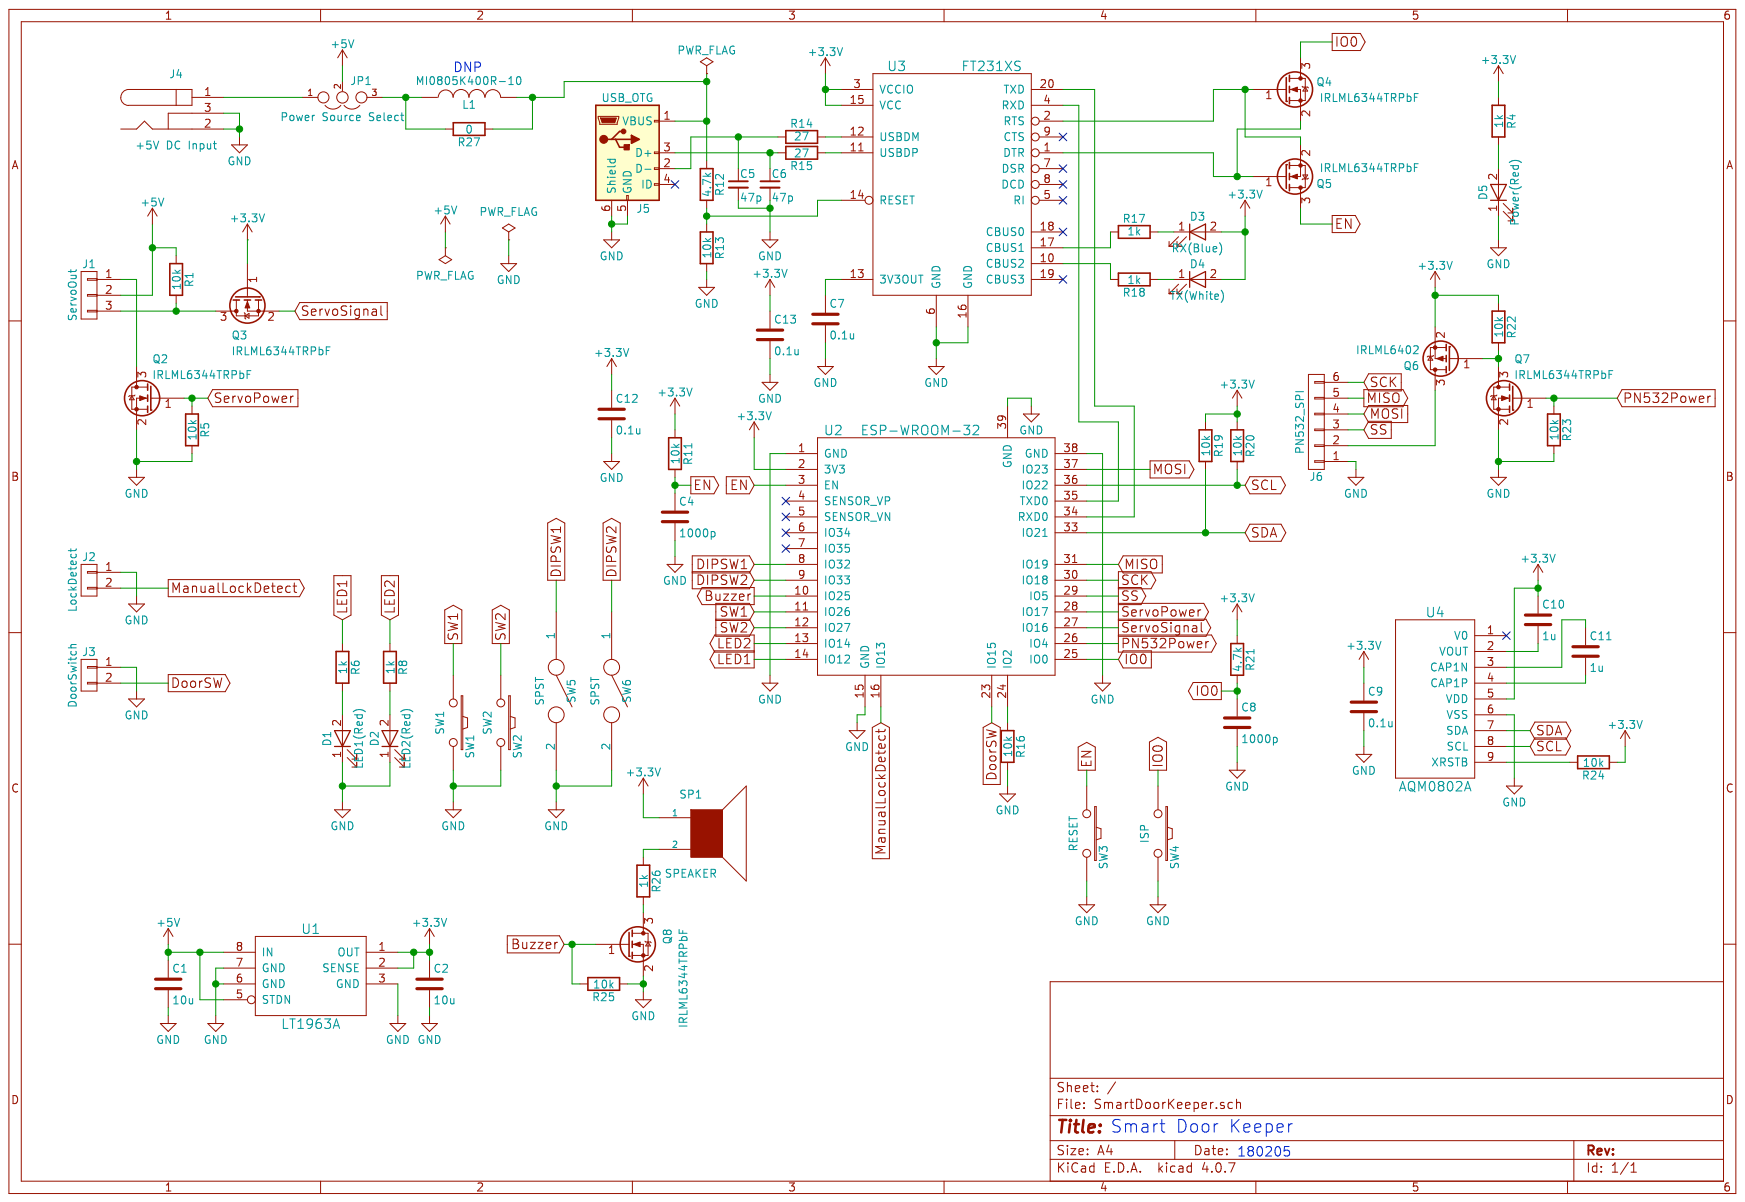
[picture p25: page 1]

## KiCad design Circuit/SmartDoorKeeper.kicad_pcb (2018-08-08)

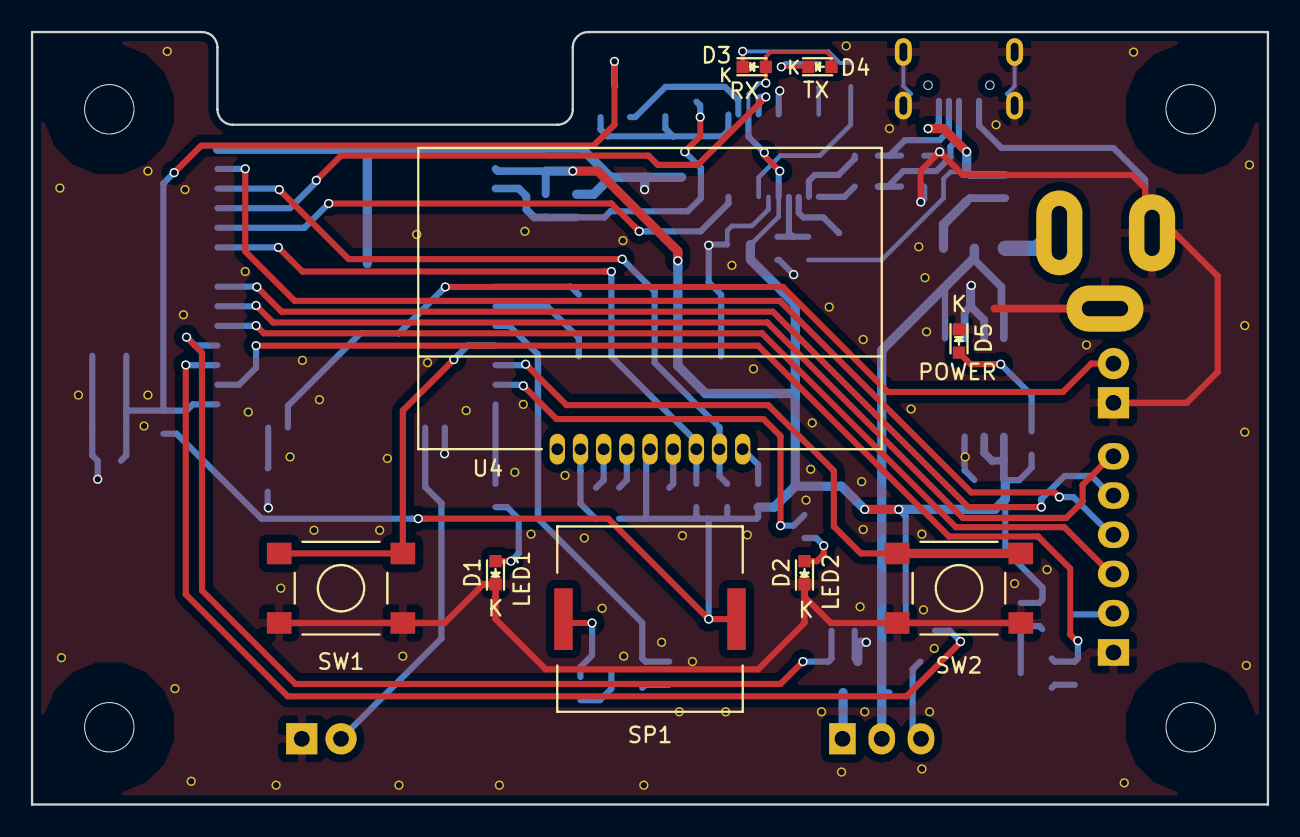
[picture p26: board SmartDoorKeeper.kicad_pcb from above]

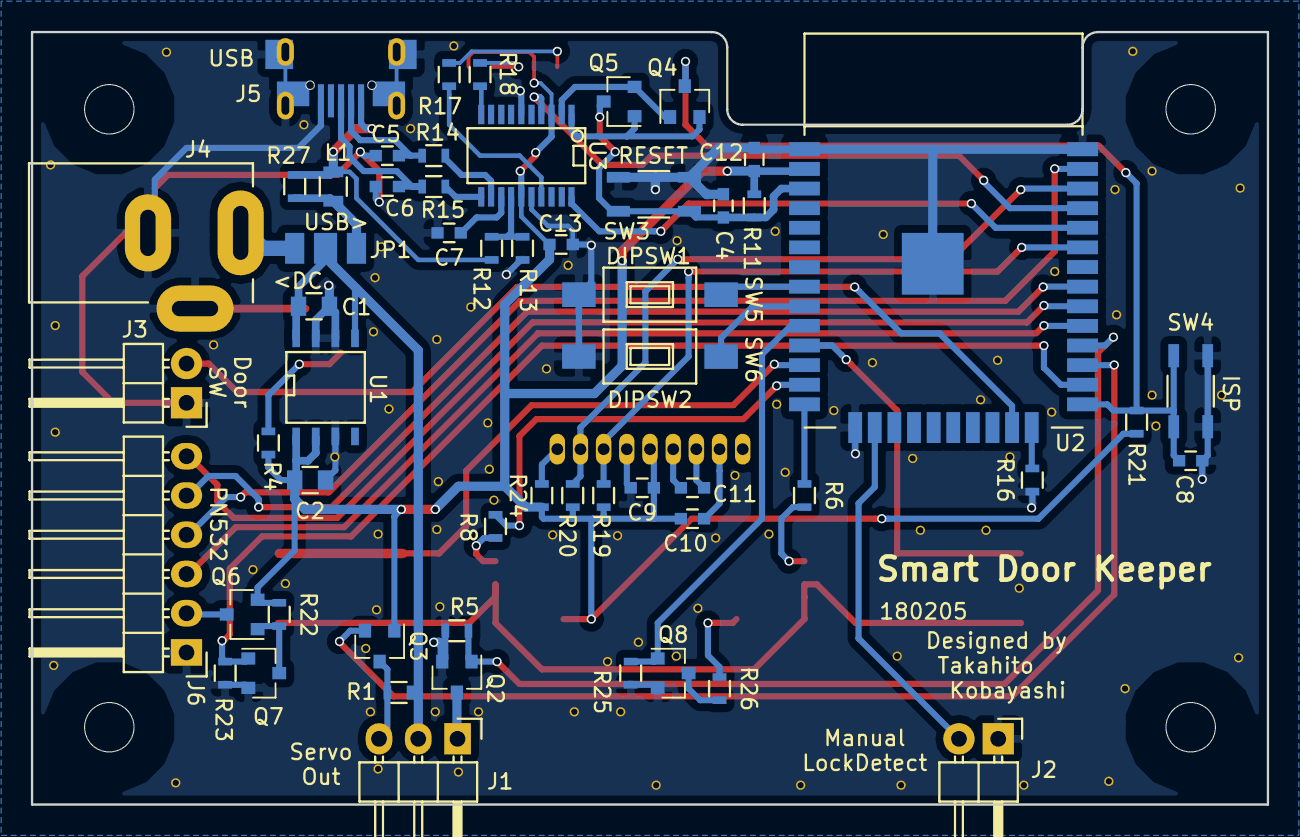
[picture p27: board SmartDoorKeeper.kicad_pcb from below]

Board: 2 copper layers, 80.0 x 50.0 mm, 65 parts (56 on the bottom side), 54 nets.

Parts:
C1, C2: 10u; C_0805
C4, C8: 1000p; C_0603
C5, C6: 47p; C_0603
C7, C9, C12, C13: 0.1u; C_0603
C10, C11: 1u; C_0603
D1: LED1(Red); LED_0603
D2: LED2(Red); LED_0603
D3: RX(Blue); LED_0603
D4: TX(White); LED_0603
D5: Power(Red); LED_0603
J1: ServoOut; Pin_Header_Angled_1x03
J2: LockDetect; Pin_Header_Angled_1x02
J3: DoorSwitch; Pin_Header_Angled_1x02
J4: +5V DC Input; MJ-179PH
J5: USB_OTG; MicroUSB_YANXINLIANG_and_ZX62-B-5PA
J6: PN532_SPI; Pin_Header_Angled_1x06
JP1: Power Source Select; SMD-Jumper-3
L1: MI0805K400R-10; R_0805
Q2, Q3, Q4, Q5, Q7, Q8: IRLML6344TRPbF; SOT-23
Q6: IRLML6402; SOT-23
R1, R5, R11, R13, R16, R19, R20, R22, R23, R24, R25: 10k; R_0603
R4, R6, R8, R17, R18, R26: 1k; R_0603
R12, R21: 4.7k; R_0603
R14, R15: 27; R_0603
R27: 0; R_0603
SP1: SPEAKER; PKLCS1212E4001-R1
SW1: SW1; 6mm_tactil_switch_SMD
SW2: SW2; 6mm_tactil_switch_SMD
SW3: RESET; SKRPACE010
SW4: ISP; SKRPACE010
SW5, SW6: SPST; SW_SPST_FSMSM
U1: LT1963A; SOIC-8-N
U2: ESP-WROOM-32
U3: FT231XS; SSOP-20
U4: AQM0802A

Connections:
+3V3: C2.1, C9.1, C10.1, C12.1, C13.1, D3.2, D4.2, Q3.1, Q6.2, R4.1, R11.1, R19.1, R20.1, R21.1, R22.1, R24.1, SP1.1, U1.1, U1.2, U2.2, U3.3, U3.15, U4.5
+5V: C1.1, J1.2, JP1.2, R1.1, U1.5, U1.8
Buzzer: Q8.1, R25.2, U2.10
DIPSW1: SW5.1, U2.8
DIPSW2: SW6.1, U2.9
DoorSW: J3.2, U2.23
EN: C4.1, Q5.3, R11.2, SW3.1, U2.3
GND: C1.2, C2.2, C4.2, C5.2, C6.2, C7.2, C8.2, C9.2, C12.2, C13.2, D1.1, D2.1, D5.1, J2.1, J3.1, J4.2, J4.3, J5.5, J5.6, J6.1, Q2.2, Q7.2, Q8.2, R5.2, R13.2, R16.2, R23.2, R25.1, SW1.2, SW2.2, SW3.2, SW4.2, SW5.2, SW6.2, U1.3, U1.6, U1.7, U2.1, U2.15, U2.38, U2.39, U3.6, U3.16, U4.6
IO0: C8.1, Q4.3, R21.2, SW4.1, U2.25
LED1: R6.1, U2.14
LED2: R8.1, U2.13
MISO: J6.5, U2.31
MOSI: J6.4, U2.37
ManualLockDetect: J2.2, U2.16
unnamed: C5.1, J5.2, R14.2
unnamed: C6.1, J5.3, R15.2
unnamed: C7.1, U3.13
unnamed: C10.2, U4.2
unnamed: C11.1, U4.3
unnamed: C11.2, U4.4
unnamed: D1.2, R6.2
unnamed: D2.2, R8.2
unnamed: D3.1, R17.1
unnamed: D4.1, R18.1
unnamed: D5.2, R4.2
unnamed: J1.1, Q2.3
unnamed: J1.3, Q3.3, R1.2
unnamed: J4.1, JP1.1
unnamed: J5.1, L1.2, R12.1, R27.1
unnamed: J6.2, Q6.3
unnamed: JP1.3, L1.1, R27.2
unnamed: Q4.1, Q5.2, U3.2
unnamed: Q4.2, Q5.1, U3.1
unnamed: Q6.1, Q7.3, R22.2
unnamed: Q8.3, R26.2
unnamed: R12.2, R13.1, U3.14
unnamed: R14.1, U3.12
unnamed: R15.1, U3.11
unnamed: R16.1, U2.24
unnamed: R17.2, U3.17
unnamed: R18.2, U3.10
unnamed: R24.2, U4.9
unnamed: R26.1, SP1.2
unnamed: U2.34, U3.20
unnamed: U2.35, U3.4
PN532Power: Q7.1, R23.1, U2.26
SCK: J6.6, U2.30
SCL: R20.2, U2.36, U4.8
SDA: R19.2, U2.33, U4.7
SS: J6.3, U2.29
SW1: SW1.1, U2.11
SW2: SW2.1, U2.12
ServoPower: Q2.1, R5.1, U2.28
ServoSignal: Q3.2, U2.27

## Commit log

2018-07-12 リポジトリを作成
2018-07-12 3Dプリントのファイルを追加
    [AssemDoorAndServo.SLDASM, AssemDoorKnob.SLDASM, AssemNfcBox.SLDASM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]
2018-07-12 3Dプリントファイルの一覧を作成
2018-07-12 画像を追加
2018-07-12 3Dプリントファイル一覧にリンクを追加
2018-07-12 READMEに3Dプリントファイルの一覧へのリンクを追加
2018-07-13 ExcelとPowerPointのファイルを追加
    [全ファイルの説明.xlsx]
2018-07-13 KiCadの設計ファイルを追加
    [SmartDoorKeyper.kicad_pcb, SmartDoorKeyper.sch]
2018-07-13 KiCadのファイルに関するReadmeを追加
2018-08-08 Smart Door Keyper -> Smart Door Keeperに変更
    [SmartDoorKeeper.kicad_pcb, SmartDoorKeeper.sch]
2018-09-05 ESP32のプログラムへのリンクを追加
2018-09-05 Submoduleとして，ESP32のプログラムを追加
2018-09-11 Androidアプリを追加
